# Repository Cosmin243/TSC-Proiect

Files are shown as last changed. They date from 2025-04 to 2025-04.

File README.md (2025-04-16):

# OpenBook – Cititor de Cărți Electronice Open-Source

OpenBook este un dispozitiv de tip e-book reader cu sursă deschisă, proiectat să fie accesibil și eficient. Creat în cadrul inițiativei TSC, dispozitivul este construit în jurul microcontrolerului ESP32-C6, oferind funcții avansate de afișare, conectivitate și consum energetic redus. Designul său este pregătit pentru producția de serie.

# Diagrama
diagramaReadme

# [BOM] - Bill of Materials

| Componentă | Descriere | Link |
|---|---|---|
| ESP32-C6-WROOM-1-N8 | Wi-Fi, BLE, Zigbee SoC Module | [Link](https://www.snapeda.com/parts/ESP32-C6-WROOM-1-N8/Espressif+Systems/view-part/) |
| BME680 | Environmental Sensor | [Link](https://www.snapeda.com/parts/BME680/Bosch/view-part/?welcome=home) |
| MCP73831 | Li-Po Battery Charging Controller | [Link](https://www.digikey.com/en/products/detail/microchip-technology/MCP73831T-2ACI-OT/1874108) |
| DS3231SN | Real-Time Clock | [Link](https://www.snapeda.com/parts/DS3231SN%23/Analog+Devices/view-part/) |
| MAX17048G+T10 | Battery Fuel Gauge | [Link](https://www.digikey.com/en/products/detail/analog-devices-inc-maxim-integrated/MAX17048G-T10/9357632) |
| W25Q512JVEIQ | 512Mb Flash Memory | [Link](https://www.snapeda.com/parts/W25Q512JVEIQ/Winbond/view-part/) |
| USB4110-GF-A | USB Type-C Connector | [Link](https://www.digikey.com/en/products/detail/amphenol-commercial-products/USB4110-GF-A/6039334) |
| 112A-TAAR-R03 | Micro SD Card Connector | [Link](https://store.comet.bg/en/Catalogue/Product/43497/) |
| XC6220A331MR-G | LDO Voltage Regulator | [Link](https://www.lcsc.com/product-detail/LDO-Voltage-Regulators_Torex-Semicon-XC6220A331MR-G_C35154.html) |
| SI1308EDL-T1-GE3 | N-Channel MOSFET | [Link](https://www.digikey.com/en/products/detail/vishay-siliconix/SI1308EDL-T1-GE3/770967) |
| DMG2305UX-7 | P-Channel MOSFET | [Link](https://www.digikey.com/en/products/detail/diodes-incorporated/DMG2305UX-7/2713557) |
| USBLC6-2SC6Y | USB ESD Protection | [Link](https://www.digikey.com/en/products/detail/stmicroelectronics/USBLC6-2SC6Y/458756) |
| MBR0530 | Schottky Diode | [Link](https://www.digikey.com/en/products/detail/onsemi/MBR0530T1G/965411) |
| CPH3225 | 11mF Supercapacitor | [Link](https://www.snapeda.com/parts/CPH3225A/Seiko+Instruments/view-part/) |
| CC0402 | Capacitor | [Link](https://componentsearchengine.com/part-view/CC0402MRX5R5BB106/YAGEO) |
| RR0402 | Resistor | [Link](https://www.snapeda.com/parts/RC0402FR-07226RL/Yageo/view-part/) |

Dispozitivul suportă mai multe surse de alimentare:

- **USB-C**: Alimentare și comunicare prin conectorul `USB4110-GF-A`, cu protecție ESD (`USBLC6-2SC6Y`)
- **Baterie Li-Po**: Încărcată prin controlerul `MCP73831`, cu indicator de stare LED
- **Backup cu supercondensator**: `CPH3225A` menține alimentarea ceasului RTC în caz de pierdere de curent

**Calea de alimentare include:**

- `XC6220A331MR-G` – LDO care furnizează 3.3V stabil pentru sistem
- `MAX17048G+T10` – Fuel gauge pentru monitorizarea capacității bateriei
- `DMG2305UX-7` – MOSFET P-Channel pentru selecția automată a sursei de alimentare
- `MBR0530` – Diodă Schottky pentru protecție la tensiuni inverse

---

## Procesare & Memorie

- `ESP32-C6-WROOM-1-N8` – Microcontroller principal cu suport pentru Wi-Fi 6, Bluetooth 5 și Zigbee 3.0
- `W25Q512JVEIQ` – Memorie Flash SPI externă de 512Mb pentru stocare extinsă
- **Slot microSD** – Permite extinderea stocării pentru datele utilizatorului

---

## Senzori & Ceas

- `BME680` – Senzor ambiental I²C ce măsoară:
  - Temperatură: -40°C până la +85°C  
  - Umiditate: 0–100% RH  
  - Presiune: 300–1100 hPa  
  - Calitatea aerului (rezistență la gaze)
- `DS3231SN` – Ceas în timp real I²C cu compensare termică, foarte precis

---

## Conectivitate & Interfețe

- **USB-C** – Pentru alimentare, încărcare și comunicare de date
- **Qwiic / STEMMA QT** – Conector I²C rapid pentru extensii externe (senzori, periferice)
- **I²C & SPI** – Utilizate pentru senzori și memorie
- **Mod Deep Sleep** – ESP32 intră în standby (~20 µA) pentru autonomie crescută

---

## Interfață Utilizator

- **Buton Reset** – Repornește dispozitivul
- **Buton Boot** – Permite accesul în modul bootloader pentru programare
- **Buton Change** – Poate fi folosit pentru interacțiuni cu conținutul afișat

# 🧷 Pini ESP32-C6

| GPIO  | Componentă |
|---|---|
| IO9 | Boot Button |
| IO2 | SD Card |
| IO4 | SD Card |
| IO21  | I2C Shared |
| IO6 | SPI Shared |
| IO22  | I2C Shared |
| IO7 | SPI Shared |
| IO0 | RTC |
| IO13  | USB Interface |
| IO19  | MAX17048 |
| IO11  | NOR Flash |
| IO12  | USB Interface |
| IO1 | RTC |
| IO8 | GPIO |
| IO15  | Buton Change |
| IO18  | RTC |
| IO17  | UART |
| IO16  | UART |
| EN | Buton Reset |

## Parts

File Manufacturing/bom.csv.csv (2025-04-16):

Qty | Value | Device | Package | Parts | Description | ARROW_PART_NUMBER | ARROW_PRICE-STOCK | AVAILABILITY | CENTROID_NOT_SPECIFIED | CHECK_PRICES | COPYRIGHT | DATASHEET | DESCRIPTION | DIGIKEY_DESCRIPTION | DIGIKEY_PART_NUMBER | HEIGHT | LEAD_FREE | MANUFACTURER_NAME | MANUFACTURER_PART_NUMBER | MF | MFR_NAME | MOUSER_PART_NUMBER | MOUSER_PRICE-STOCK | MOUSER_TESTING_PART_NUMBER | MOUSER_TESTING_PRICE-STOCK | MP | MPN | PACKAGE | POPULARITY | PREFIX | PRICE | PROD_ID | PURCHASE-URL | ROHS | SNAPEDA_LINK | SPICEMODEL | SPICEPREFIX | TEMPERATURE_RANGE_HIGH | TEMPERATURE_RANGE_LOW | TP_SIGNAL_NAME | VALUE
1 |  | ADAFRUIT_LEDCHIP-LED0603 | ADAFRUIT_CHIP-LED0603 | CHG_LED | LED
1 |  | SJ | SJ | SJ1 | SMD solder JUMPER |  |  |  |  |  |  |  |  |  |  |  |  |  |  |  |  |  |  |  |  |  |  |  | 3
8 | 0.1uF/50V | ESP32_WROVER_EAGLE-LTSPICE_CC0402 | ESP32_WROVER_EAGLE-LTSPICE_C0402 | EPD_C5, EPD_C6, EPD_C7, EPD_C8, EPD_C9, EPD_C10, EPD_C11, EPD_C12 | CAPACITOR, European symbol |  |  |  |  |  |  |  |  |  |  |  |  |  |  |  |  |  |  |  |  |  |  |  |  |  |  |  |  |  |  | NONE | C
1 | 0.47 | ESP32_WROVER_EAGLE-LTSPICE_RR0402 | ESP32_WROVER_EAGLE-LTSPICE_R0402 | R3 | RESISTOR, European symbol |  |  |  |  |  |  |  |  |  |  |  |  |  |  |  |  |  |  |  |  |  |  |  |  |  |  |  |  |  |  | NONE | R
1 | 100K | ESP32_WROVER_EAGLE-LTSPICE_RR0402 | ESP32_WROVER_EAGLE-LTSPICE_R0402 | R1_PWRUSB | RESISTOR, European symbol
6 | 100nF | ESP32_WROVER_EAGLE-LTSPICE_CC0402 | ESP32_WROVER_EAGLE-LTSPICE_C0402 | C1, C2, C4_USB, C7, C8, C_DELAY | CAPACITOR, European symbol |  |  |  |  |  |  |  |  |  |  |  |  |  |  |  |  |  |  |  |  |  |  |  |  |  |  |  |  |  |  | NONE | C
1 | 100uF TANT | RCL_CPOL-EUCT3528 | RCL_CT3528 | C11 | POLARIZED CAPACITOR, European symbol |  |  |  |  |  |  |  |  |  |  |  |  |  |  |  |  |  |  |  |  |  |  |  | 0 |  |  |  |  |  |  |  | C
13 | 10K | ESP32_WROVER_EAGLE-LTSPICE_RR0402 | ESP32_WROVER_EAGLE-LTSPICE_R0402 | R1_PINH, R1_PINH1, R2-PINH, R2-PINH1, R5, R6, R7, R8, R9, R10, R_BOOT, R_CHANGE, R_RESET | RESISTOR, European symbol
2 | 10k | ESP32_WROVER_EAGLE-LTSPICE_RR0402 | ESP32_WROVER_EAGLE-LTSPICE_R0402 | R1, R_CL1 | RESISTOR, European symbol
1 | 10k | ESP32_WROVER_EAGLE-LTSPICE_RR0402 | ESP32_WROVER_EAGLE-LTSPICE_R0402 | R4 | RESISTOR, European symbol |  |  |  |  |  |  |  |  |  |  |  |  |  |  |  |  |  |  |  |  |  |  |  |  |  |  |  |  |  |  | NONE | R
4 | 10uF | ESP32_WROVER_EAGLE-LTSPICE_CC0402 | ESP32_WROVER_EAGLE-LTSPICE_C0402 | C3, C5, C6, C10 | CAPACITOR, European symbol |  |  |  |  |  |  |  |  |  |  |  |  |  |  |  |  |  |  |  |  |  |  |  |  |  |  |  |  |  |  | NONE | C
1 | 112A-TAAR-R03_ATTEND | 112A-TAAR-R03_ATTEND | 112ATAARR03ATTEND | J4 | Micro SD Card Socket, Push-Push Type, Top Mount, SMT, H=1.83mm, 10u |  |  |  |  |  |  |  | Micro SD Card Socket | Push-Push Type | Top Mount | SMT | H=1.83mm | 10u |  |  | 1.9mm |  | ATTEND | 112A-TAAR-R03 ATTEND
1 | 15 | ESP32_WROVER_EAGLE-LTSPICE_RR0402 | ESP32_WROVER_EAGLE-LTSPICE_R0402 | R_CAPACITOR | RESISTOR, European symbol
2 | 1uF/50V | ESP32_WROVER_EAGLE-LTSPICE_CC0402 | ESP32_WROVER_EAGLE-LTSPICE_C0402 | EPD_C1, EPD_C2 | CAPACITOR, European symbol |  |  |  |  |  |  |  |  |  |  |  |  |  |  |  |  |  |  |  |  |  |  |  |  |  |  |  |  |  |  | NONE | C
1 | 2.2 | ESP32_WROVER_EAGLE-LTSPICE_RR0402 | ESP32_WROVER_EAGLE-LTSPICE_R0402 | R2 | RESISTOR, European symbol
1 | 200 | ESP32_WROVER_EAGLE-LTSPICE_RR0402 | ESP32_WROVER_EAGLE-LTSPICE_R0402 | R1_BAT | RESISTOR, European symbol
2 | 20V/4.2A/52mO/1.4W | ESP32_WROVER_SPARKFUN-DISCRETESEMI_MOSFET_PCH-DMG2305UX-7 | ESP32_WROVER_SPARKFUN-DISCRETESEMI_SOT23-3 | Q2, Q3 | P-channel MOSFETs |  |  |  |  |  |  |  |  |  |  |  |  |  |  |  |  |  |  |  |  |  |  |  |  |  |  | TRAN-14388 |  |  |  |  |  |  |  |  | 20V/4.2A/52mO/1.4W
1 | 2k | ESP32_WROVER_EAGLE-LTSPICE_RR0402 | ESP32_WROVER_EAGLE-LTSPICE_R0402 | R2_BAT | RESISTOR, European symbol
5 | 4.7uF | ESP32_WROVER_EAGLE-LTSPICE_CC0402 | ESP32_WROVER_EAGLE-LTSPICE_C0402 | C1_BAT, C1_BAT1, C1_BAT2, C2_BAT, C5_USB | CAPACITOR, European symbol |  |  |  |  |  |  |  |  |  |  |  |  |  |  |  |  |  |  |  |  |  |  |  |  |  |  |  |  |  |  | NONE | C
1 | 4.7uF/25V | ESP32_WROVER_EAGLE-LTSPICE_CC0402 | ESP32_WROVER_EAGLE-LTSPICE_C0402 | C4 | CAPACITOR, European symbol |  |  |  |  |  |  |  |  |  |  |  |  |  |  |  |  |  |  |  |  |  |  |  |  |  |  |  |  |  |  | NONE | C
1 | 5K1 | ESP32_WROVER_EAGLE-LTSPICE_RR0402 | ESP32_WROVER_EAGLE-LTSPICE_R0402 | R2-USB1 | RESISTOR, European symbol
1 | 5k1 | ESP32_WROVER_EAGLE-LTSPICE_RR0402 | ESP32_WROVER_EAGLE-LTSPICE_R0402 | R2-USB | RESISTOR, European symbol
1 | 68uH | 744043680IND_4828-WE-TPC_WRE | IND_4828-WE-TPC_WRE | L1 |  |  |  |  |  |  | Copyright (C) 2024 Ultra Librarian. All rights reserved. |  |  |  |  |  |  |  | 744043680 |  | Wurth Electronics
1 | BD5229G-TR | BD5229G-TR | SOT95P280X125-5N | IC1 | Voltage Detector with Adjustable Delay Time: CMOS processes are utilized to develop high precision, low current consumption CMOS reset ICs that allow arbitrary setting of the delay time. The extensive lineup includes both Nch Open Drain and CMOS output types in a wide range of detection voltages (from 2.3V to 6.0V, in 0.1V steps), enabling selection of the ideal solution based on customer requirements. In addition, the entire series is of course both lead-free and RoHS-compliant. |  |  |  |  |  |  |  | Voltage Detector with Adjustable Delay Time: CMOS processes are utilized to develop high precision | low current consumption CMOS reset ICs that allow arbitrary setting of the delay time. The extensive lineup includes both Nch Open Drain and CMOS output types in a wide range of detection voltages (from 2.3V to 6.0V | in 0.1V steps) | enabling selection of the ideal solution based on customer requirements. In addition | the entire series is of course both lead-free and RoHS-compliant. |  |  | 1.25mm |  | ROHM Semiconductor | BD5229G-TR |  |  | 755-BD5229G-TR | https://www.mouser.co.uk/ProductDetail/ROHM-Semiconductor/BD5229G-TR?qs=4kLU8WoGk0vvnhrrYwdszw%3D%3D
3 | BUTTON_CUSYOMV1 | BUTTON_CUSYOMV1 | MYBUTTON | BOOT_BUTTON, CHANGE_BUTTON, RESET_BUTTON
1 | CPH3225A | CPH3225A | CAPCP3225X100N | C10_SUPERCAP | Cap 0.011F 3.3V 1210 Flat Check availability |  |  | Not in stock |  | https://www.snapeda.com/parts/CPH3225A/Seiko+Instruments/view-part/?ref=eda |  |  | 11 mF (EDLC) Supercapacitor 3.3 V 1210 (3225 Metric) - - |  |  |  |  |  |  | Seiko Instruments |  |  |  |  |  | CPH3225A |  | 1210 Seiko |  |  | None |  | https://www.snapeda.com/api/url_track_click_mouser/?unipart_id=562593&manufacturer=Seiko Instruments&part_name=CPH3225A&search_term=None |  | https://www.snapeda.com/parts/CPH3225A/Seiko+Instruments/view-part/?ref=snap
1 | DS3231SN# | DS3231SN# | SOIC127P1032X265-16N | U3 | Real Time Clock Serial 16-Pin SOIC W T/R Check availability |  |  | In Stock |  | https://www.snapeda.com/parts/DS3231SN%23/Analog+Devices/view-part/?ref=eda |  |  | Extremely Accurate I²C-Integrated RTC/TCXO/Crystal |  |  |  |  |  |  | Analog Devices |  |  |  |  |  | DS3231SN# |  | SOIC-16 Maxim |  |  | None |  | https://www.snapeda.com/api/url_track_click_mouser/?unipart_id=99048&manufacturer=Analog Devices&part_name=DS3231SN#&search_term=None |  | https://www.snapeda.com/parts/DS3231SN%23/Analog+Devices/view-part/?ref=snap
1 | ESP32-C6-WROOM-1-N8 | ESP32-C6-WROOM-1-N8 | XCVR_ESP32-C6-WROOM-1-N8 | U2 | Check availability |  |  | In Stock |  | https://www.snapeda.com/parts/ESP32-C6-WROOM-1-N8/Espressif+Systems/view-part/?ref=eda |  |  | Multiprotocol Modules ESP32-C6 module | Wi-Fi 6 in 2.4 GHz band | Bluetooth 5 | Zigbee 3.0 and Thread. ESP34-WROOM Compatible - ENGINEERING SAMPLE |  |  |  |  |  |  | Espressif Systems |  |  |  |  |  | ESP32-C6-WROOM-1-N8 |  | None |  |  | None |  |  |  | https://www.snapeda.com/parts/ESP32-C6-WROOM-1-N8/Espressif+Systems/view-part/?ref=snap
1 | ESP32C6_VARISTORCN1812 | ESP32C6_VARISTORCN1812 | ESP32C6_VARISTOR_CT/CN1812 | PFMF.050.1 | VARISTOR |  |  |  |  |  |  |  |  |  |  |  |  |  |  |  |  |  |  |  |  |  |  |  | 0
2 | ESP32_WROVER_AVX---SD0805S020S1R0_AVX_SD0805S020S1R0_0_0AVX_SD0805S020S1R0_0_0 | ESP32_WROVER_AVX---SD0805S020S1R0_AVX_SD0805S020S1R0_0_0AVX_SD0805S020S1R0_0_0 | ESP32_WROVER_AVX---SD0805S020S1R0_AVX_SD0805S020S1R0_0 | D2, D7 | Schottky Barrier Rectifier Diode |  |  |  | No |  |  | http://datasheets.avx.com/schottky.pdf |  | DIODE SCHOTTKY 20V 1A 0805 | 478-7800-1-ND |  | yes |  |  | AVX |  | 581-SD0805S020S1R0 |  |  |  |  |  | 0805 (2012 metric) |  | D |  |  |  | yes |  |  |  | +125°C | -55°C
1 | ESP32_WROVER_BME680_BME680 | ESP32_WROVER_BME680_BME680 | ESP32_WROVER_BME680_PSON80P300X300X100-8N | SENSOR2 | Integrated Environmental Unit |  |  | Unavailable |  |  |  |  | Integrated Environmental Unit |  |  |  |  |  |  | Bosch Sensortec |  |  |  |  |  | BME680 |  | LGA-8 Bosch Tools |  |  | None
1 | ESP32_WROVER_SPARKFUN-IC-POWER_MCP73831 | ESP32_WROVER_SPARKFUN-IC-POWER_MCP73831 | ESP32_WROVER_SPARKFUN-IC-POWER_SOT23-5 | MCP73831 | MCP73831T Li-Ion, Li-Pol Controller |  |  |  |  |  |  |  |  |  |  |  |  |  |  |  |  |  |  |  |  |  |  |  |  |  |  | IC-09995
1 | FH34SRJ-24S-0.5SH_99_ | FH34SRJ-24S-0.5SH_99_ | FH34SRJ24S05SH99 | J1 | (0.50mm) Surface Mount, Right Angle |  |  |  |  |  |  |  | 24 Position FFC | FPC Connector Contacts | (0.50mm) Surface Mount | Right Angle |  |  | 1.1mm |  | Hirose | FH34SRJ-24S-0.5SH(99) |  |  | 798-FH34SRJ24S05SH99 | https://www.mouser.co.uk/ProductDetail/Hirose-Connector/FH34SRJ-24S-0.5SH99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
1 | MAX17048G+T10 | MAX17048G+T10 | SON50P200X200X80-9N | U4 | Check availability |  |  | In Stock |  | https://www.snapeda.com/parts/MAX17048G+T10/Analog+Devices/view-part/?ref=eda |  |  | 3µA 1-Cell/2-Cell Fuel Gauge with ModelGauge |  |  |  |  |  |  | Analog Devices |  |  |  |  |  | MAX17048G+T10 |  | TDFN-8 Maxim |  |  | None |  | https://www.snapeda.com/api/url_track_click_mouser/?unipart_id=329239&manufacturer=Analog Devices&part_name=MAX17048G+T10&search_term=None |  | https://www.snapeda.com/parts/MAX17048G+T10/Analog+Devices/view-part/?ref=snap
3 | MBR0530 | MBR0530 | SOD3716X135N | D3, D4, D5 | ON SEMICONDUCTOR - MBR0530 - DIODE, SCHOTTKY, 0.5A, 30V, SOD-123 |  |  | In Stock |  | https://www.snapeda.com/parts/MBR0530/Onsemi/view-part/?ref=eda |  |  | Diode Schottky 30 V 500mA Surface Mount SOD-123 |  |  |  |  |  |  | ON Semiconductor |  |  |  |  |  | MBR0530 |  | SOD-123-2 ON Semiconductor |  |  | None |  | https://www.snapeda.com/api/url_track_click_mouser/?unipart_id=179458&manufacturer=ON Semiconductor&part_name=MBR0530&search_term=None |  | https://www.snapeda.com/parts/MBR0530/Onsemi/view-part/?ref=snap
6 | PGB1010603MR | PGB1010603MR | DIOC1608X36N | D6, D8, D9, D10, D11, D12 | Check availability |  |  | In Stock |  | https://www.snapeda.com/parts/PGB1010603MR/Littelfuse/view-part/?ref=eda |  |  | 150V (Typ) Clamp - Ipp Tvs Diode Surface Mount 0603 (1608 Metric) |  |  |  |  |  |  | Littelfuse Inc. |  |  |  |  |  | PGB1010603MR |  | 0603 Littelfuse Inc. |  |  | None |  | https://www.snapeda.com/api/url_track_click_mouser/?unipart_id=5659453&manufacturer=Littelfuse Inc.&part_name=PGB1010603MR&search_term=None |  | https://www.snapeda.com/parts/PGB1010603MR/Littelfuse/view-part/?ref=snap
1 | QWIIC_RIGHT_ANGLE | QWIIC_CONNECTORJS-1MM | JST04_1MM_RA | J3 | SparkFun I2C Standard Qwiic Connector |  |  |  |  |  |  |  |  |  |  |  |  |  |  |  |  |  |  |  |  |  |  |  |  |  |  | CONN-13694 |  |  |  |  |  |  |  |  | QWIIC_RIGHT_ANGLE
1 | SAMACSYS_PARTS_USB4110-GF-A | SAMACSYS_PARTS_USB4110-GF-A | SAMACSYS_PARTS_USB4110GFA | J2 | CONN USB 2.0 TYPE-C R/A SMT |  |  |  |  |  |  |  | CONN USB 2.0 TYPE-C R/A SMT |  |  | 3.26mm |  | GCT (GLOBAL CONNECTOR TECHNOLOGY) | USB4110-GF-A |  |  | 640-USB4110-GF-A | https://www.mouser.co.uk/ProductDetail/GCT/USB4110-GF-A?qs=KUoIvG%2F9IlYiZvIXQjyJeA%3D%3D
1 | SI1308EDL-T1-GE3 | SI1308EDL-T1-GE3 | SOT65P210X110-3N | Q1 | MOSFET N-Ch 30V 1.5A TrenchFET SC70 Vishay Si1308EDL-T1-GE3 N-channel MOSFET Transistor, 1.5 A, 30 V, 3-Pin SC-70 |  |  | In Stock |  | https://www.snapeda.com/parts/SI1308EDL-T1-GE3/Vishay+Siliconix/view-part/?ref=eda |  |  | Si1308EDL-T1-GE3 N-channel MOSFET Transistor | 1.5 A | 30 V | 3-Pin SC-70 | Siliconix / Vishay SI1308EDL-T1-GE3 |  |  |  |  |  |  | Vishay Siliconix |  |  |  |  |  | SI1308EDL-T1-GE3 |  | SOT-323 Vishay Semiconductor |  |  | None |  | https://www.snapeda.com/api/url_track_click_mouser/?unipart_id=274603&manufacturer=Vishay Siliconix&part_name=SI1308EDL-T1-GE3&search_term=None |  | https://www.snapeda.com/parts/SI1308EDL-T1-GE3/Vishay+Siliconix/view-part/?ref=snap
17 | TPTP20R | TPTP20R | TP20R | TP1, TP2, TP3, TP4, TP5, TP6, TP7, TP8, TP9, TP10, TP11, TP12, TP13, TP14, TP15, TP16, TP17 | Test pad |  |  |  |  |  |  |  |  |  |  |  |  |  |  |  |  |  |  |  |  |  |  |  | 2
1 | USBLC6-2SC6Y | USBLC6-2SC6Y | SOT95P280X145-6N | D1 | Low Cap. ESD Protection Auto SOT-23-6 STMicroelectronics USBLC6-2SC6Y, Dual Uni-Directional TVS Diode Array, 6-Pin SOT-23 |  |  | In Stock |  | https://www.snapeda.com/parts/USBLC6-2SC6Y/STMicroelectronics/view-part/?ref=eda |  |  | 17V Clamp 5A (8/20µs) Ipp Tvs Diode Surface Mount SOT-23-6 |  |  |  |  |  |  | STMicroelectronics |  |  |  |  |  | USBLC6-2SC6Y |  | SOT-23-6 STMicroelectronics |  |  | None |  |  |  | https://www.snapeda.com/parts/USBLC6-2SC6Y/STMicroelectronics/view-part/?ref=snap
1 | W25Q512JVEIQ | W25Q512JVEIQ | SON127P600X800X80-9N | U1 | Check availability |  |  | In Stock |  | https://www.snapeda.com/parts/W25Q512JVEIQ/Winbond+Electronics/view-part/?ref=eda |  |  | FLASH - NOR Memory IC 512Mb (64M x 8) SPI - Quad I/O 133 MHz 8-WSON (8x6) |  |  |  |  |  |  | Winbond Electronics |  |  |  |  |  | W25Q512JVEIQ |  | Package |  |  | None |  |  |  | https://www.snapeda.com/parts/W25Q512JVEIQ/Winbond+Electronics/view-part/?ref=snap
1 | XC6220A331MR-G | XC6220A331MR-G | SOT95P280X120-5N | IC2 | LDO Voltage Regulators |  |  |  |  |  |  |  | LDO Voltage Regulators |  |  | 1.2mm |  | Torex | XC6220A331MR-G |  |  | 865-XC6220A331MR-G | https://www.mouser.co.uk/ProductDetail/Torex-Semiconductor/XC6220A331MR-G?qs=AsjdqWjXhJ8ZSWznL1J0gg%3D%3D

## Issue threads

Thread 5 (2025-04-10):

[PCB] - errori de copper width

aylaa2, 2025-04-10:
la piesa u4 ai erori de copper width
poti sa le rezolvi cu edit footprint si sa schimbi dimensiunea,  pad-urile au o lățime mai mică decât cea permisă de regulile de proiectare (DRC)

Closed 2025-04-16.

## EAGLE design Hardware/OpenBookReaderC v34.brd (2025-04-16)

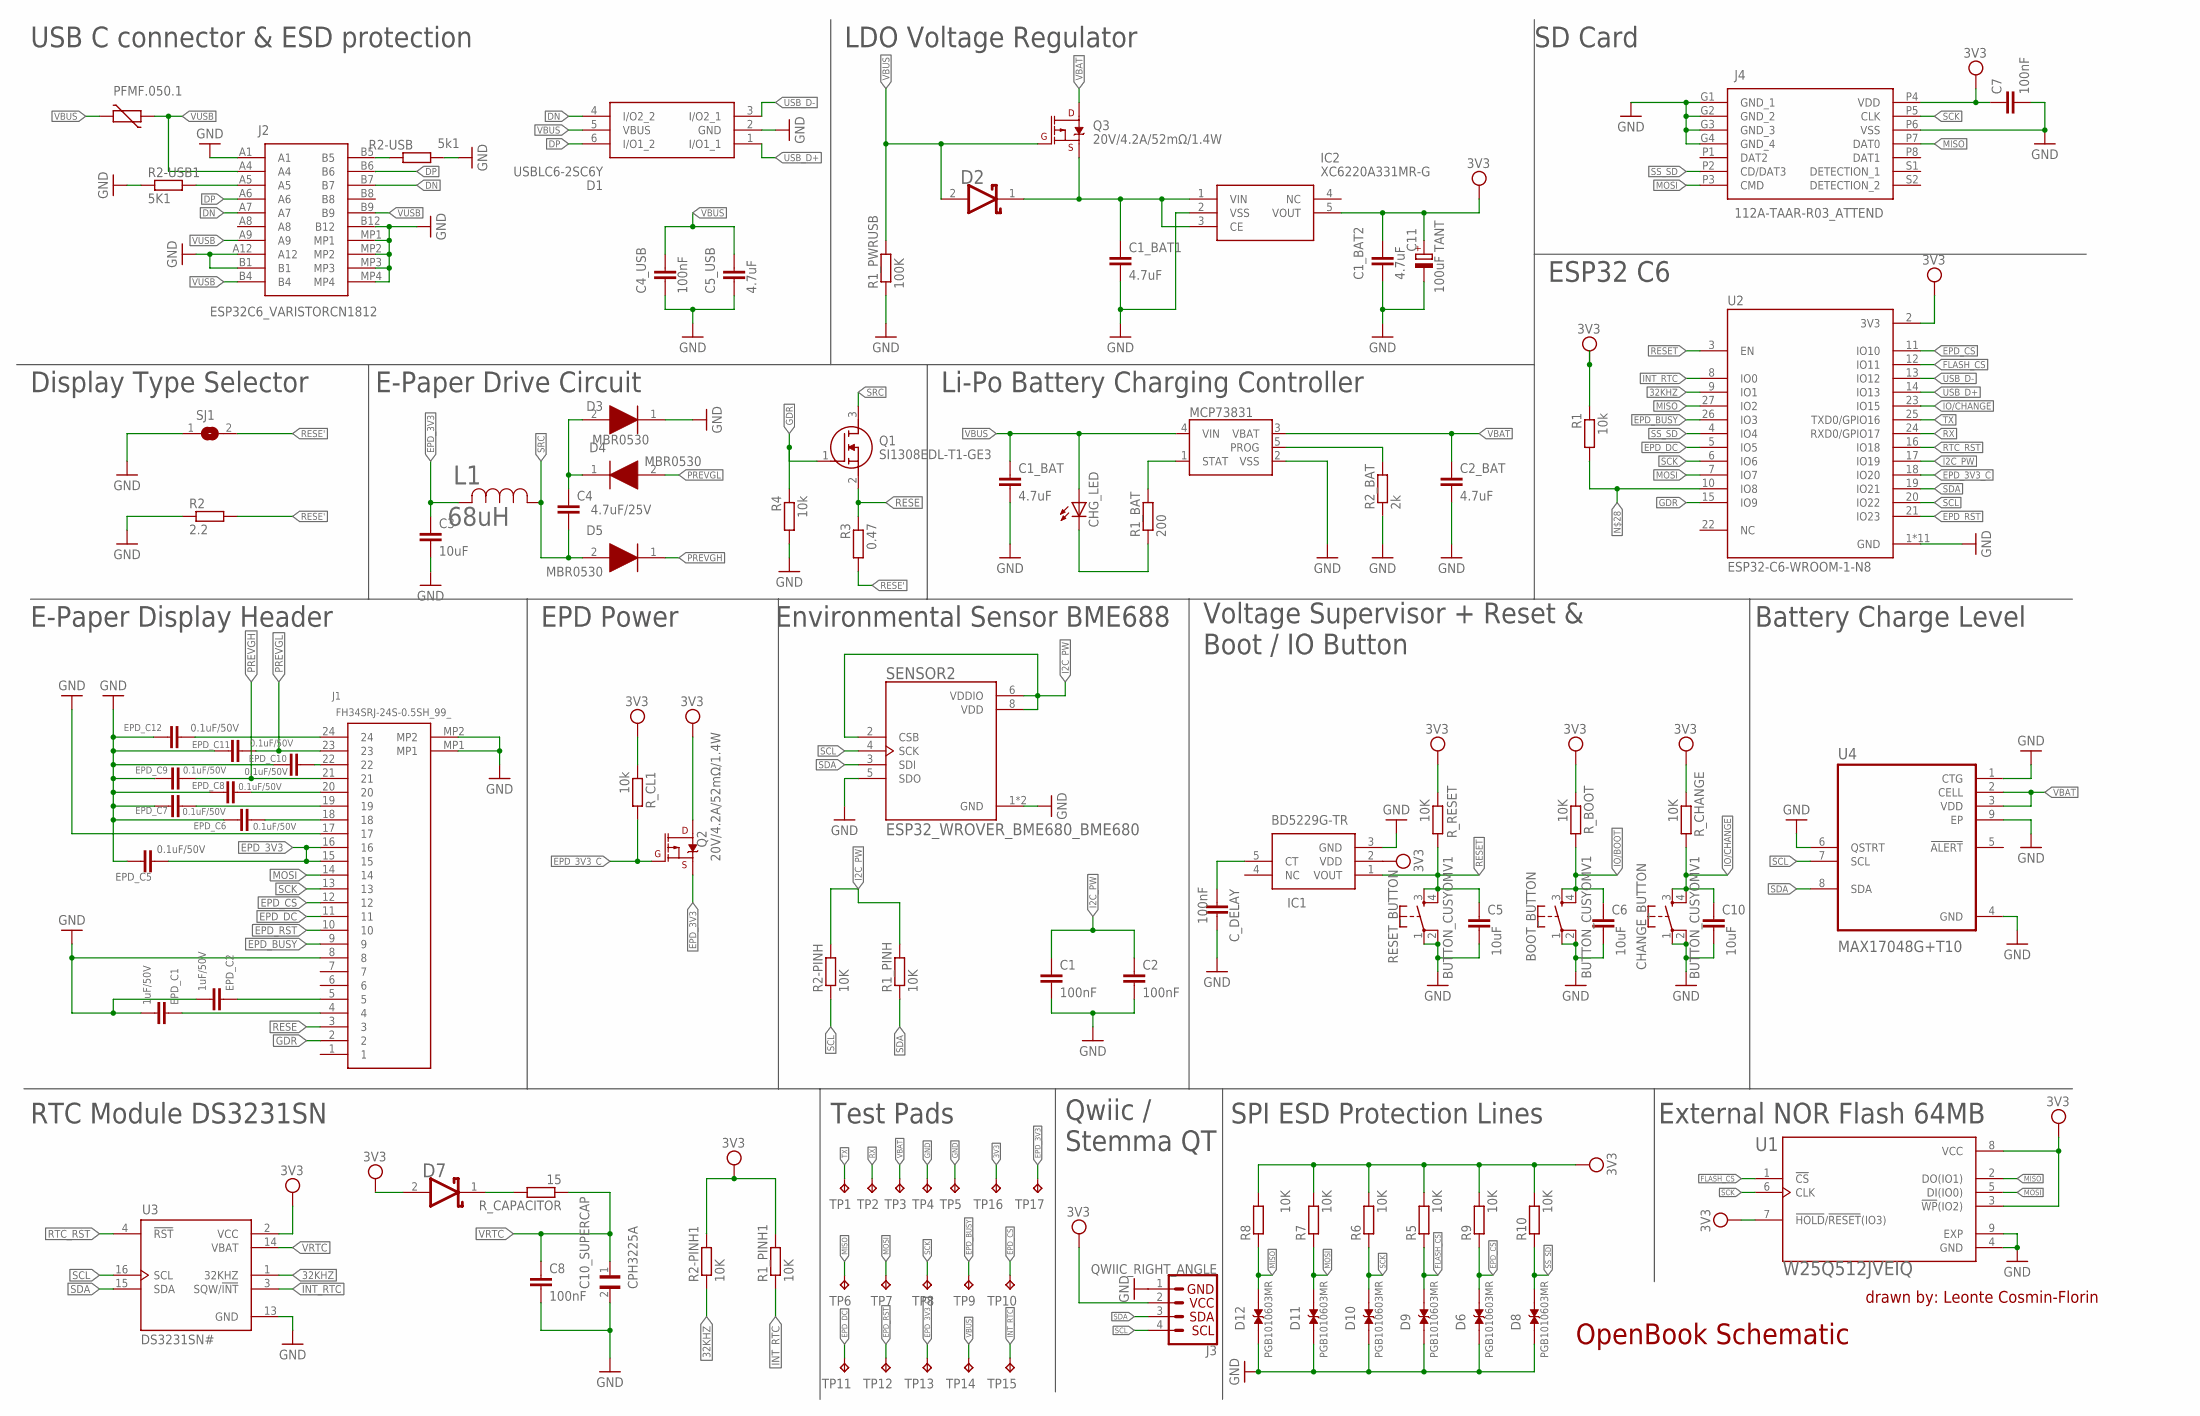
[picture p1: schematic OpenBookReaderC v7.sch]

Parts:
BOOT_BUTTON: BUTTON_CUSYOMV1; MYBUTTON
C1, C2, C4_USB, C7, C8: 100nF; ESP32_WROVER_EAGLE-LTSPICE_C0402
C1_BAT, C1_BAT1, C1_BAT2, C2_BAT, C5_USB: 4.7uF; ESP32_WROVER_EAGLE-LTSPICE_C0402
C3, C5, C6, C10: 10uF; ESP32_WROVER_EAGLE-LTSPICE_C0402
C4: 4.7uF/25V; ESP32_WROVER_EAGLE-LTSPICE_C0402
C10_SUPERCAP: CPH3225A; CAPCP3225X100N
C11: 100uF TANT; RCL_CT3528
CHANGE_BUTTON: BUTTON_CUSYOMV1; MYBUTTON
CHG_LED: ADAFRUIT_LEDCHIP-LED0603; ADAFRUIT_CHIP-LED0603
C_DELAY: 100nF; ESP32_WROVER_EAGLE-LTSPICE_C0402
D1: USBLC6-2SC6Y; SOT95P280X145-6N
D2, D7: ESP32_WROVER_AVX---SD0805S020S1R0_AVX_SD0805S020S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; ESP32_WROVER_AVX---SD0805S020S1R0_AVX_SD0805S020S1R0_0
D3, D4, D5: MBR0530; SOD3716X135N
D6, D8, D9, D10, D11, D12: PGB1010603MR; DIOC1608X36N
EPD_C1, EPD_C2: 1uF/50V; ESP32_WROVER_EAGLE-LTSPICE_C0402
EPD_C5, EPD_C6, EPD_C7, EPD_C8, EPD_C9, EPD_C10, EPD_C11, EPD_C12: 0.1uF/50V; ESP32_WROVER_EAGLE-LTSPICE_C0402
IC1: BD5229G-TR; SOT95P280X125-5N
IC2: XC6220A331MR-G; SOT95P280X120-5N
J1: FH34SRJ-24S-0.5SH_99_; FH34SRJ24S05SH99
J2: SAMACSYS_PARTS_USB4110-GF-A; SAMACSYS_PARTS_USB4110GFA
J3: QWIIC_RIGHT_ANGLE; JST04_1MM_RA
J4: 112A-TAAR-R03_ATTEND; 112ATAARR03ATTEND
L1: 68uH; IND_4828-WE-TPC_WRE
MCP73831: ESP32_WROVER_SPARKFUN-IC-POWER_MCP73831; ESP32_WROVER_SPARKFUN-IC-POWER_SOT23-5
PFMF.050.1: ESP32C6_VARISTORCN1812; ESP32C6_VARISTOR_CT/CN1812
Q1: SI1308EDL-T1-GE3; SOT65P210X110-3N
Q2, Q3: 20V/4.2A/52mΩ/1.4W; ESP32_WROVER_SPARKFUN-DISCRETESEMI_SOT23-3
R1, R4: 10k; ESP32_WROVER_EAGLE-LTSPICE_R0402
R1_BAT: 200; ESP32_WROVER_EAGLE-LTSPICE_R0402
R1_PINH, R1_PINH1, R2-PINH, R2-PINH1, R5, R6, R7, R8, R9, R10: 10K; ESP32_WROVER_EAGLE-LTSPICE_R0402
R1_PWRUSB: 100K; ESP32_WROVER_EAGLE-LTSPICE_R0402
R2: 2.2; ESP32_WROVER_EAGLE-LTSPICE_R0402
R2-USB: 5k1; ESP32_WROVER_EAGLE-LTSPICE_R0402
R2-USB1: 5K1; ESP32_WROVER_EAGLE-LTSPICE_R0402
R2_BAT: 2k; ESP32_WROVER_EAGLE-LTSPICE_R0402
R3: 0.47; ESP32_WROVER_EAGLE-LTSPICE_R0402
RESET_BUTTON: BUTTON_CUSYOMV1; MYBUTTON
R_BOOT: 10K; ESP32_WROVER_EAGLE-LTSPICE_R0402
R_CAPACITOR: 15; ESP32_WROVER_EAGLE-LTSPICE_R0402
R_CHANGE: 10K; ESP32_WROVER_EAGLE-LTSPICE_R0402
R_CL1: 10k; ESP32_WROVER_EAGLE-LTSPICE_R0402
R_RESET: 10K; ESP32_WROVER_EAGLE-LTSPICE_R0402
SENSOR2: ESP32_WROVER_BME680_BME680; ESP32_WROVER_BME680_PSON80P300X300X100-8N
SJ1: SJ
TP1, TP2, TP3, TP4, TP5, TP6, TP7, TP8, TP9, TP10, TP11, TP12, TP13, TP14, TP15, TP16, TP17: TPTP20R; TP20R
U1: W25Q512JVEIQ; SON127P600X800X80-9N
U2: ESP32-C6-WROOM-1-N8; XCVR_ESP32-C6-WROOM-1-N8
U3: DS3231SN#; SOIC127P1032X265-16N
U4: MAX17048G+T10; SON50P200X200X80-9N

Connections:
3V3: C1_BAT2.1, C7.1, C11.+, D7.2 (ANODE), IC1.2 (VDD), IC2.5 (VOUT), J3.2, J4.P4 (VDD), Q2.3 (D), R1.1, R1_PINH1.2, R2-PINH1.2, R5.2, R6.2, R7.2, R8.2, R9.2, R10.2, R_BOOT.1, R_CHANGE.1, R_CL1.1, R_RESET.1, TP16.TP, U1.3 (!WP!(IO2)), U1.7 (!HOLD!/!RESET!(IO3)), U1.8 (VCC), U2.2 (3V3), U3.2 (VCC)
32KHZ: R2-PINH1.1, U2.9 (IO1), U3.1 (32KHZ)
DN: D1.4 (I/O2_2), J2.A7, J2.B7
DP: D1.6 (I/O1_2), J2.A6, J2.B6
EPD_3V3: C3.1, EPD_C5.1, J1.15, J1.16, L1.2, Q2.2 (S), TP17.TP
EPD_3V3_C: Q2.1 (G), R_CL1.2, TP13.TP, U2.18 (IO20)
EPD_BUSY: J1.9, TP9.TP, U2.26 (IO3)
EPD_CS: D6.2, J1.12, R9.1, TP10.TP, U2.11 (IO10)
EPD_DC: J1.11, TP11.TP, U2.5 (IO5)
EPD_RST: J1.10, TP12.TP, U2.21 (IO23)
FLASH_CS: D9.2, R5.1, U1.1 (!CS), U2.12 (IO11)
GDR: J1.2, Q1.1 (G), R4.1, U2.15 (IO9)
GND: BOOT_BUTTON.1, BOOT_BUTTON.2, C1.2, C1_BAT.2, C1_BAT1.2, C1_BAT2.2, C2.2, C2_BAT.2, C3.2, C4_USB.2, C5.2, C5_USB.2, C6.2, C7.2, C8.2, C10.2, C10_SUPERCAP.2, C11.-, CHANGE_BUTTON.1, CHANGE_BUTTON.2, C_DELAY.2, D1.2 (GND), D3.1 (K), D6.1, D8.1, D9.1, D10.1, D11.1, D12.1, EPD_C1.2, EPD_C2.2, EPD_C5.2, EPD_C6.2, EPD_C7.2, EPD_C8.2, EPD_C9.2, EPD_C10.2, EPD_C11.2, EPD_C12.2, IC1.3 (GND), IC2.2 (VSS), J1.8, J1.17, J1.MP1, J1.MP2, J2.A1, J2.A12, J2.B1, J2.B12, J2.MP1, J2.MP2, J2.MP3, J2.MP4, J3.1, J4.G1 (GND_1), J4.G2 (GND_2), J4.G3 (GND_3), J4.G4 (GND_4), J4.P6 (VSS), MCP73831.2 (VSS), R1_PWRUSB.1, R2.1, R2-USB.2, R2-USB1.1, R2_BAT.1, R4.2, RESET_BUTTON.1, RESET_BUTTON.2, SENSOR2.1 (GND), SENSOR2.5 (SDO), SENSOR2.7 (GND), SJ1.1, TP4.TP, TP5.TP, U1.4 (GND), U1.9 (EXP), U2.1 (GND), U2.28 (GND), U2.29_1 (GND), U2.29_2 (GND), U2.29_3 (GND), U2.29_4 (GND), U2.29_5 (GND), U2.29_6 (GND), U2.29_7 (GND), U2.29_8 (GND), U2.29_9 (GND), U3.13 (GND), U4.1 (CTG), U4.4 (GND), U4.6 (QSTRT), U4.9 (EP)
I2C_PW: C1.1, C2.1, R1_PINH.2, R2-PINH.2, SENSOR2.2 (CSB), SENSOR2.6 (VDDIO), SENSOR2.8 (VDD), U2.17 (IO19)
INT_RTC: R1_PINH1.1, TP15.TP, U2.8 (IO0), U3.3 (SQW/!INT)
IO/BOOT: BOOT_BUTTON.3, BOOT_BUTTON.4, C6.1, R_BOOT.2
IO/CHANGE: C10.1, CHANGE_BUTTON.3, CHANGE_BUTTON.4, R_CHANGE.2, U2.23 (IO15)
MISO: D12.2, J4.P7 (DAT0), R8.1, TP6.TP, U1.2 (DO(IO1)), U2.27 (IO2)
MOSI: D11.2, J1.14, J4.P3 (CMD), R7.1, TP7.TP, U1.5 (DI(IO0)), U2.7 (IO7)
unnamed: EPD_C1.1, J1.4
unnamed: EPD_C2.1, J1.5
unnamed: D7.1 (CATHODE), R_CAPACITOR.2
unnamed: EPD_C6.1, J1.18
unnamed: EPD_C7.1, J1.19
unnamed: EPD_C8.1, J1.20
unnamed: C_DELAY.1, IC1.5 (CT)
unnamed: EPD_C10.1, J1.22
unnamed: C4.1, D3.2 (A), D4.1 (K)
unnamed: EPD_C12.1, J1.24
unnamed: J2.B5, R2-USB.1
unnamed: MCP73831.1 (STAT), R1_BAT.2
unnamed: CHG_LED.C, R1_BAT.1
unnamed: MCP73831.5 (PROG), R2_BAT.2
unnamed: C1_BAT1.1, D2.1 (CATHODE), IC2.1 (VIN), IC2.3 (CE), Q3.2 (S)
unnamed: J2.A5, R2-USB1.2
unnamed: R1.2, U2.10 (IO8)
PREVGH: D5.1 (K), EPD_C9.1, J1.21
PREVGL: D4.2 (A), EPD_C11.1, J1.23
RESE: J1.3, Q1.2 (S), R3.1
RESE': R2.2, R3.2, SJ1.2
RESET: C5.1, IC1.1 (VOUT), RESET_BUTTON.3, RESET_BUTTON.4, R_RESET.2, U2.3 (EN)
RTC_RST: U2.16 (IO18), U3.4 (!RST)
RX: TP2.TP, U2.24 (RXD0/GPIO17)
SCK: D10.2, J1.13, J4.P5 (CLK), R6.1, TP8.TP, U1.6 (CLK), U2.6 (IO6)
SCL: J3.4, R2-PINH.1, SENSOR2.4 (SCK), U2.20 (IO22), U3.16 (SCL), U4.7 (SCL)
SDA: J3.3, R1_PINH.1, SENSOR2.3 (SDI), U2.19 (IO21), U3.15 (SDA), U4.8 (SDA)
SRC: C4.2, D5.2 (A), L1.1, Q1.3 (D)
SS_SD: D8.2, J4.P2 (CD/DAT3), R10.1, U2.4 (IO4)
TX: TP1.TP, U2.25 (TXD0/GPIO16)
USB_D+: D1.1 (I/O1_1), U2.14 (IO13)
USB_D-: D1.3 (I/O2_1), U2.13 (IO12)
VBAT: C2_BAT.1, MCP73831.3 (VBAT), Q3.3 (D), TP3.TP, U4.2 (CELL), U4.3 (VDD)
VBUS: C1_BAT.1, C4_USB.1, C5_USB.1, CHG_LED.A, D1.5 (VBUS), D2.2 (ANODE), MCP73831.4 (VIN), PFMF.050.1.2, Q3.1 (G), R1_PWRUSB.2, TP14.TP
VRTC: C8.1, C10_SUPERCAP.1, R_CAPACITOR.1, U3.14 (VBAT)
VUSB: J2.A4, J2.A9, J2.B4, J2.B9, PFMF.050.1.1

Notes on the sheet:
E-Paper Display Header
RTC Module DS3231SN
Test Pads
Qwiic / Stemma QT
SPI ESD Protection Lines
External NOR Flash 64MB
Battery Charge Level
Voltage Supervisor + Reset & Boot / IO Button
Environmental Sensor BME688
EPD Power
Display Type Selector
E-Paper Drive Circuit
Li-Po Battery Charging Controller
ESP32 C6
SD Card
LDO Voltage Regulator
USB C connector & ESD protection
OpenBook Schematic
drawn by: Leonte Cosmin-Florin

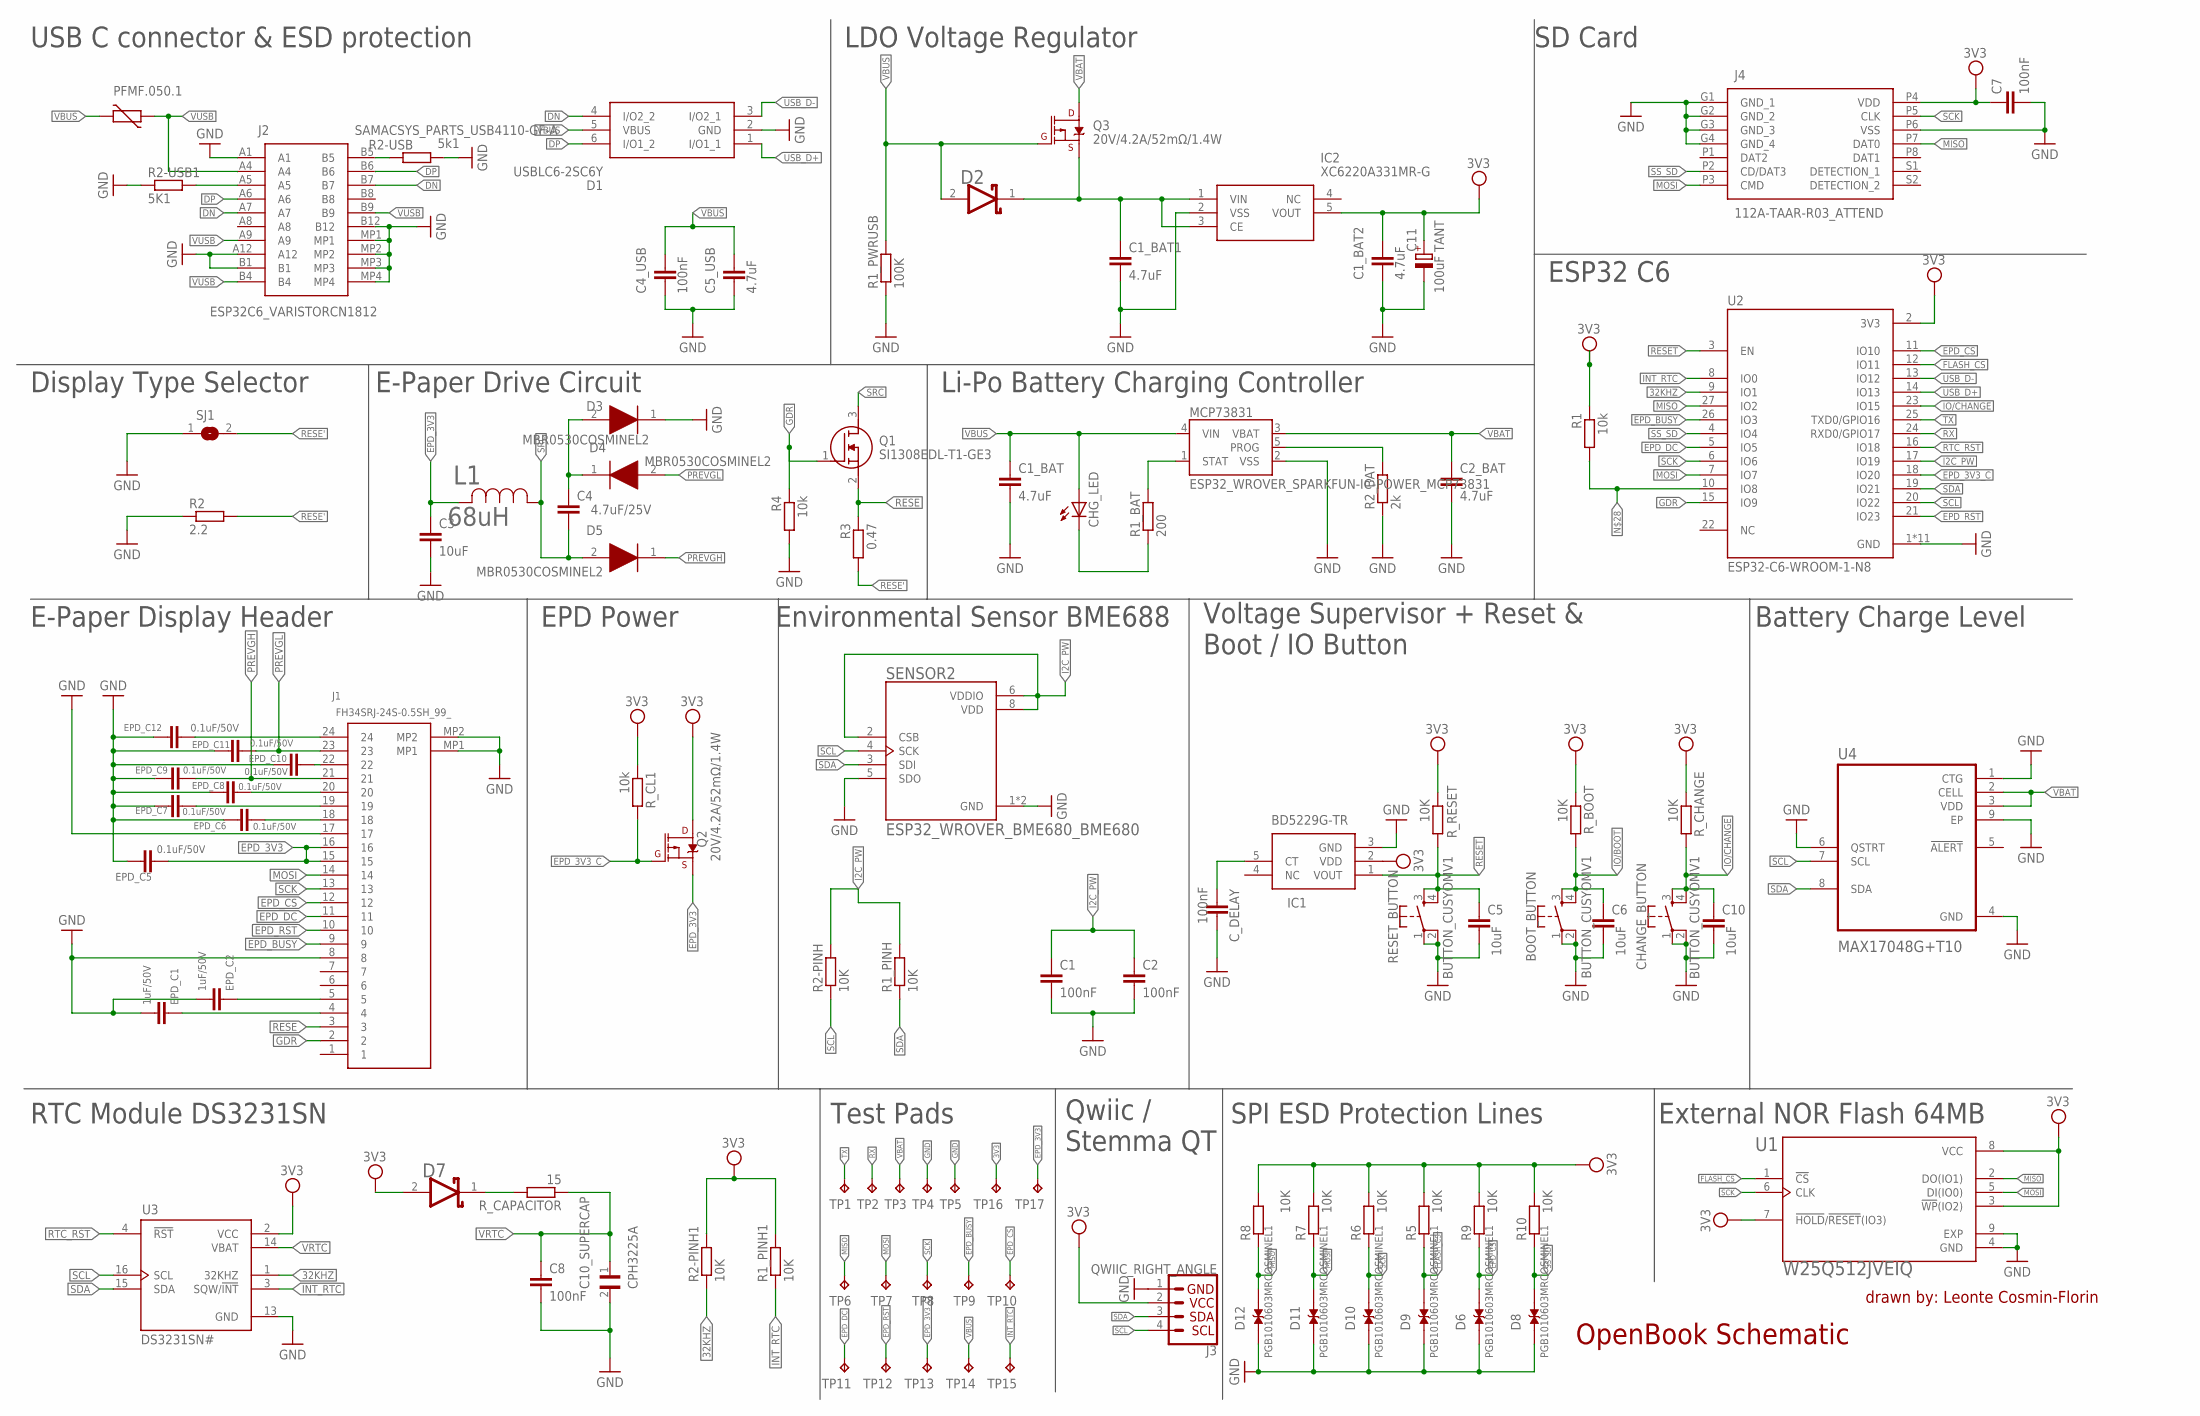
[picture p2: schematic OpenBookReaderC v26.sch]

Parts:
BOOT_BUTTON: BUTTON_CUSYOMV1; MYBUTTON
C1, C2, C4_USB, C7, C8: 100nF; ESP32_WROVER_EAGLE-LTSPICE_C0402
C1_BAT, C1_BAT1, C1_BAT2, C2_BAT, C5_USB: 4.7uF; ESP32_WROVER_EAGLE-LTSPICE_C0402
C3, C5, C6, C10: 10uF; ESP32_WROVER_EAGLE-LTSPICE_C0402
C4: 4.7uF/25V; ESP32_WROVER_EAGLE-LTSPICE_C0402
C10_SUPERCAP: CPH3225A; CAPCP3225X100N
C11: 100uF TANT; RCL_CT3528
CHANGE_BUTTON: BUTTON_CUSYOMV1; MYBUTTON
CHG_LED: ADAFRUIT_LEDCHIP-LED0603; ADAFRUIT_CHIP-LED0603
C_DELAY: 100nF; ESP32_WROVER_EAGLE-LTSPICE_C0402
D1: USBLC6-2SC6Y; SOT95P280X145-6N
D2, D7: ESP32_WROVER_AVX---SD0805S020S1R0_AVX_SD0805S020S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; ESP32_WROVER_AVX---SD0805S020S1R0_AVX_SD0805S020S1R0_0
D3, D4, D5: MBR0530COSMINEL2; SOD3716X135N
D6, D8, D9, D10, D11, D12: PGB1010603MRCOSMINEL1; DIOC1608X36N
EPD_C1, EPD_C2: 1uF/50V; ESP32_WROVER_EAGLE-LTSPICE_C0402
EPD_C5, EPD_C6, EPD_C7, EPD_C8, EPD_C9, EPD_C10, EPD_C11, EPD_C12: 0.1uF/50V; ESP32_WROVER_EAGLE-LTSPICE_C0402
IC1: BD5229G-TR; SOT95P280X125-5N
IC2: XC6220A331MR-G; SOT95P280X120-5N
J1: FH34SRJ-24S-0.5SH_99_; FH34SRJ24S05SH99
J2: SAMACSYS_PARTS_USB4110-GF-A; SAMACSYS_PARTS_USB4110GFA
J3: QWIIC_RIGHT_ANGLE; JST04_1MM_RA
J4: 112A-TAAR-R03_ATTEND; 112ATAARR03ATTEND
L1: 68uH; IND_4828-WE-TPC_WRE
MCP73831: ESP32_WROVER_SPARKFUN-IC-POWER_MCP73831; ESP32_WROVER_SPARKFUN-IC-POWER_SOT23-5
PFMF.050.1: ESP32C6_VARISTORCN1812; ESP32C6_VARISTOR_CT/CN1812
Q1: SI1308EDL-T1-GE3; SOT65P210X110-3N
Q2, Q3: 20V/4.2A/52mΩ/1.4W; ESP32_WROVER_SPARKFUN-DISCRETESEMI_SOT23-3
R1, R4: 10k; ESP32_WROVER_EAGLE-LTSPICE_R0402
R1_BAT: 200; ESP32_WROVER_EAGLE-LTSPICE_R0402
R1_PINH, R1_PINH1, R2-PINH, R2-PINH1, R5, R6, R7, R8, R9, R10: 10K; ESP32_WROVER_EAGLE-LTSPICE_R0402
R1_PWRUSB: 100K; ESP32_WROVER_EAGLE-LTSPICE_R0402
R2: 2.2; ESP32_WROVER_EAGLE-LTSPICE_R0402
R2-USB: 5k1; ESP32_WROVER_EAGLE-LTSPICE_R0402
R2-USB1: 5K1; ESP32_WROVER_EAGLE-LTSPICE_R0402
R2_BAT: 2k; ESP32_WROVER_EAGLE-LTSPICE_R0402
R3: 0.47; ESP32_WROVER_EAGLE-LTSPICE_R0402
RESET_BUTTON: BUTTON_CUSYOMV1; MYBUTTON
R_BOOT: 10K; ESP32_WROVER_EAGLE-LTSPICE_R0402
R_CAPACITOR: 15; ESP32_WROVER_EAGLE-LTSPICE_R0402
R_CHANGE: 10K; ESP32_WROVER_EAGLE-LTSPICE_R0402
R_CL1: 10k; ESP32_WROVER_EAGLE-LTSPICE_R0402
R_RESET: 10K; ESP32_WROVER_EAGLE-LTSPICE_R0402
SENSOR2: ESP32_WROVER_BME680_BME680; ESP32_WROVER_BME680_PSON80P300X300X100-8N
SJ1: SJ
TP1, TP2, TP3, TP4, TP5, TP6, TP7, TP8, TP9, TP10, TP11, TP12, TP13, TP14, TP15, TP16, TP17: TP; TP20R
U1: W25Q512JVEIQ; SON127P600X800X80-9N
U2: ESP32-C6-WROOM-1-N8; XCVR_ESP32-C6-WROOM-1-N8
U3: DS3231SN#; SOIC127P1032X265-16N
U4: MAX17048G+T10; SON50P200X200X80-9N

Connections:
3V3: C1_BAT2.1, C7.1, C11.+, D7.2 (ANODE), IC1.2 (VDD), IC2.5 (VOUT), J3.2, J4.P4 (VDD), Q2.3 (D), R1.1, R1_PINH1.2, R2-PINH1.2, R5.2, R6.2, R7.2, R8.2, R9.2, R10.2, R_BOOT.1, R_CHANGE.1, R_CL1.1, R_RESET.1, TP16.TP, U1.3 (!WP!(IO2)), U1.7 (!HOLD!/!RESET!(IO3)), U1.8 (VCC), U2.2 (3V3), U3.2 (VCC)
32KHZ: R2-PINH1.1, U2.9 (IO1), U3.1 (32KHZ)
DN: D1.4 (I/O2_2), J2.A7, J2.B7
DP: D1.6 (I/O1_2), J2.A6, J2.B6
EPD_3V3: C3.1, EPD_C5.1, J1.15, J1.16, L1.2, Q2.2 (S), TP17.TP
EPD_3V3_C: Q2.1 (G), R_CL1.2, TP13.TP, U2.18 (IO20)
EPD_BUSY: J1.9, TP9.TP, U2.26 (IO3)
EPD_CS: D6.2, J1.12, R9.1, TP10.TP, U2.11 (IO10)
EPD_DC: J1.11, TP11.TP, U2.5 (IO5)
EPD_RST: J1.10, TP12.TP, U2.21 (IO23)
FLASH_CS: D9.2, R5.1, U1.1 (!CS), U2.12 (IO11)
GDR: J1.2, Q1.1 (G), R4.1, U2.15 (IO9)
GND: BOOT_BUTTON.1, BOOT_BUTTON.2, C1.2, C1_BAT.2, C1_BAT1.2, C1_BAT2.2, C2.2, C2_BAT.2, C3.2, C4_USB.2, C5.2, C5_USB.2, C6.2, C7.2, C8.2, C10.2, C10_SUPERCAP.2, C11.-, CHANGE_BUTTON.1, CHANGE_BUTTON.2, C_DELAY.2, D1.2 (GND), D3.1 (K), D6.1, D8.1, D9.1, D10.1, D11.1, D12.1, EPD_C1.2, EPD_C2.2, EPD_C5.2, EPD_C6.2, EPD_C7.2, EPD_C8.2, EPD_C9.2, EPD_C10.2, EPD_C11.2, EPD_C12.2, IC1.3 (GND), IC2.2 (VSS), J1.8, J1.17, J1.MP1, J1.MP2, J2.A1, J2.A12, J2.B1, J2.B12, J2.MP1, J2.MP2, J2.MP3, J2.MP4, J3.1, J4.G1 (GND_1), J4.G2 (GND_2), J4.G3 (GND_3), J4.G4 (GND_4), J4.P6 (VSS), MCP73831.2 (VSS), R1_PWRUSB.1, R2.1, R2-USB.2, R2-USB1.1, R2_BAT.1, R4.2, RESET_BUTTON.1, RESET_BUTTON.2, SENSOR2.1 (GND), SENSOR2.5 (SDO), SENSOR2.7 (GND), SJ1.1, TP4.TP, TP5.TP, U1.4 (GND), U1.9 (EXP), U2.1 (GND), U2.28 (GND), U2.29_1 (GND), U2.29_2 (GND), U2.29_3 (GND), U2.29_4 (GND), U2.29_5 (GND), U2.29_6 (GND), U2.29_7 (GND), U2.29_8 (GND), U2.29_9 (GND), U3.13 (GND), U4.1 (CTG), U4.4 (GND), U4.6 (QSTRT), U4.9 (EP)
I2C_PW: C1.1, C2.1, R1_PINH.2, R2-PINH.2, SENSOR2.2 (CSB), SENSOR2.6 (VDDIO), SENSOR2.8 (VDD), U2.17 (IO19)
INT_RTC: R1_PINH1.1, TP15.TP, U2.8 (IO0), U3.3 (SQW/!INT)
IO/BOOT: BOOT_BUTTON.3, BOOT_BUTTON.4, C6.1, R_BOOT.2
IO/CHANGE: C10.1, CHANGE_BUTTON.3, CHANGE_BUTTON.4, R_CHANGE.2, U2.23 (IO15)
MISO: D12.2, J4.P7 (DAT0), R8.1, TP6.TP, U1.2 (DO(IO1)), U2.27 (IO2)
MOSI: D11.2, J1.14, J4.P3 (CMD), R7.1, TP7.TP, U1.5 (DI(IO0)), U2.7 (IO7)
unnamed: EPD_C1.1, J1.4
unnamed: EPD_C2.1, J1.5
unnamed: D7.1 (CATHODE), R_CAPACITOR.2
unnamed: EPD_C6.1, J1.18
unnamed: EPD_C7.1, J1.19
unnamed: EPD_C8.1, J1.20
unnamed: C_DELAY.1, IC1.5 (CT)
unnamed: EPD_C10.1, J1.22
unnamed: C4.1, D3.2 (A), D4.1 (K)
unnamed: EPD_C12.1, J1.24
unnamed: J2.B5, R2-USB.1
unnamed: MCP73831.1 (STAT), R1_BAT.2
unnamed: CHG_LED.C, R1_BAT.1
unnamed: MCP73831.5 (PROG), R2_BAT.2
unnamed: C1_BAT1.1, D2.1 (CATHODE), IC2.1 (VIN), IC2.3 (CE), Q3.2 (S)
unnamed: J2.A5, R2-USB1.2
unnamed: R1.2, U2.10 (IO8)
PREVGH: D5.1 (K), EPD_C9.1, J1.21
PREVGL: D4.2 (A), EPD_C11.1, J1.23
RESE: J1.3, Q1.2 (S), R3.1
RESE': R2.2, R3.2, SJ1.2
RESET: C5.1, IC1.1 (VOUT), RESET_BUTTON.3, RESET_BUTTON.4, R_RESET.2, U2.3 (EN)
RTC_RST: U2.16 (IO18), U3.4 (!RST)
RX: TP2.TP, U2.24 (RXD0/GPIO17)
SCK: D10.2, J1.13, J4.P5 (CLK), R6.1, TP8.TP, U1.6 (CLK), U2.6 (IO6)
SCL: J3.4, R2-PINH.1, SENSOR2.4 (SCK), U2.20 (IO22), U3.16 (SCL), U4.7 (SCL)
SDA: J3.3, R1_PINH.1, SENSOR2.3 (SDI), U2.19 (IO21), U3.15 (SDA), U4.8 (SDA)
SRC: C4.2, D5.2 (A), L1.1, Q1.3 (D)
SS_SD: D8.2, J4.P2 (CD/DAT3), R10.1, U2.4 (IO4)
TX: TP1.TP, U2.25 (TXD0/GPIO16)
USB_D+: D1.1 (I/O1_1), U2.14 (IO13)
USB_D-: D1.3 (I/O2_1), U2.13 (IO12)
VBAT: C2_BAT.1, MCP73831.3 (VBAT), Q3.3 (D), TP3.TP, U4.2 (CELL), U4.3 (VDD)
VBUS: C1_BAT.1, C4_USB.1, C5_USB.1, CHG_LED.A, D1.5 (VBUS), D2.2 (ANODE), MCP73831.4 (VIN), PFMF.050.1.2, Q3.1 (G), R1_PWRUSB.2, TP14.TP
VRTC: C8.1, C10_SUPERCAP.1, R_CAPACITOR.1, U3.14 (VBAT)
VUSB: J2.A4, J2.A9, J2.B4, J2.B9, PFMF.050.1.1

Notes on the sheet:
E-Paper Display Header
RTC Module DS3231SN
Test Pads
Qwiic / Stemma QT
SPI ESD Protection Lines
External NOR Flash 64MB
Battery Charge Level
Voltage Supervisor + Reset & Boot / IO Button
Environmental Sensor BME688
EPD Power
Display Type Selector
E-Paper Drive Circuit
Li-Po Battery Charging Controller
ESP32 C6
SD Card
LDO Voltage Regulator
USB C connector & ESD protection
OpenBook Schematic
drawn by: Leonte Cosmin-Florin

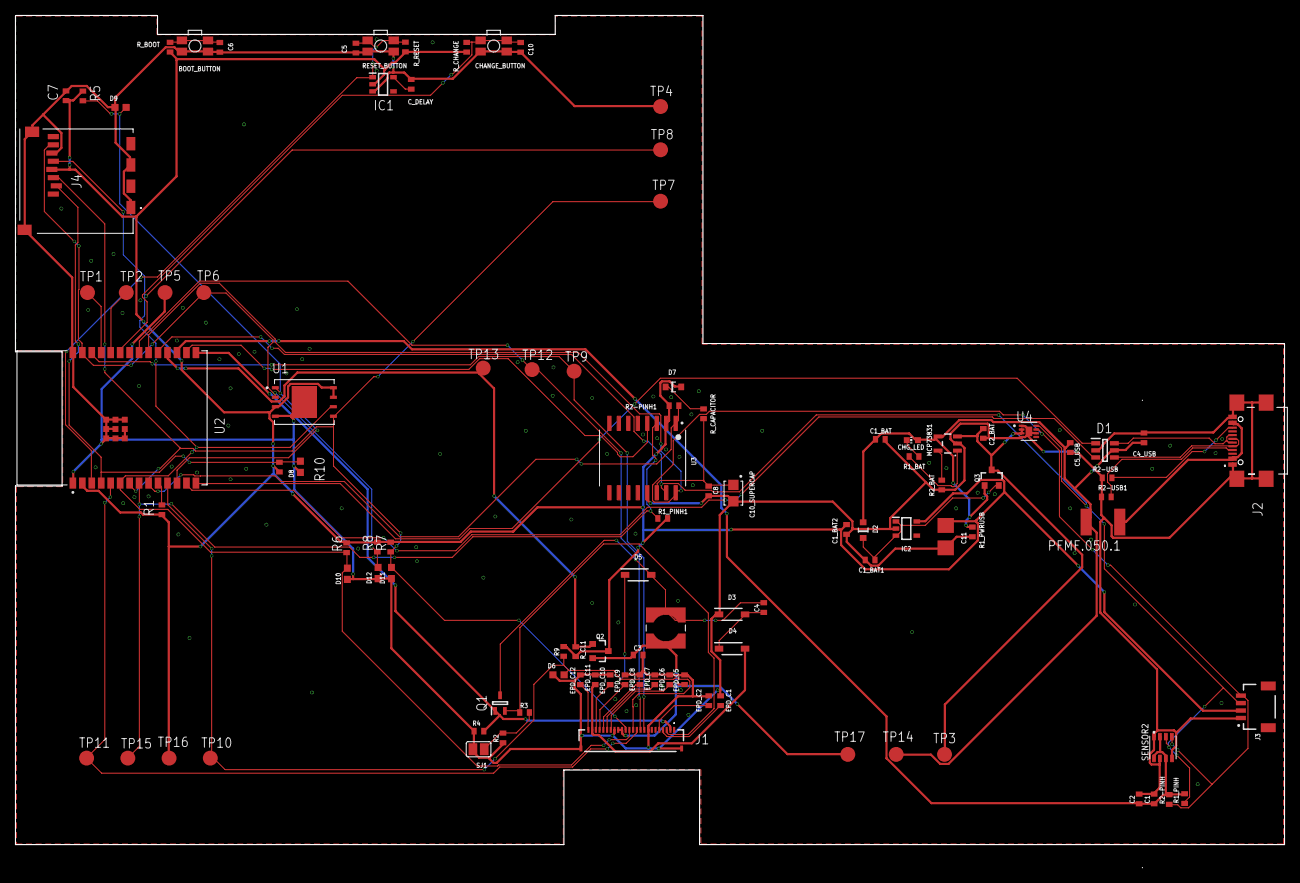
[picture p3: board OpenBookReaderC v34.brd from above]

Board: 2 copper layers, 170.2 x 114.3 mm, 103 parts (0 on the bottom side), 55 nets.

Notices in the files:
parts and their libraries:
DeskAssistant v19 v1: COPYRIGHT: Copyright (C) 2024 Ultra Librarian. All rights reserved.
